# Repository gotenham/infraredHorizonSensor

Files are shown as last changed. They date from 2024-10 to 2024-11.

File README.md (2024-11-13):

# infraredHorizonSensor
A project to build a prototype infrared horizon sensor using a thermopile imaging array for CubeSat orbital attitude determination.

Check out the [video presentation summarising the research here](https://youtu.be/ipN0h2YGPOc?si=D6N8nWLN3bS8p15P).

Traditional image-based horizon sensors provide orientation information by detecting planetary edges against the background of space, a process often performed using visible light cameras due to the typically limited resolution of infrared imaging sensors. This study illustrates some of the advantages of using the infrared band for horizon detection, and explores recent advancements in sub-pixel edge localisation techniques, specifically the Zernike polynomials, to improve the performance of low-resolution thermal imaging sensors for horizon detection. To evaluate the utility of this technique, a prototype infrared horizon sensor and simulated infrared orbital view test stand was built to assess its performance.

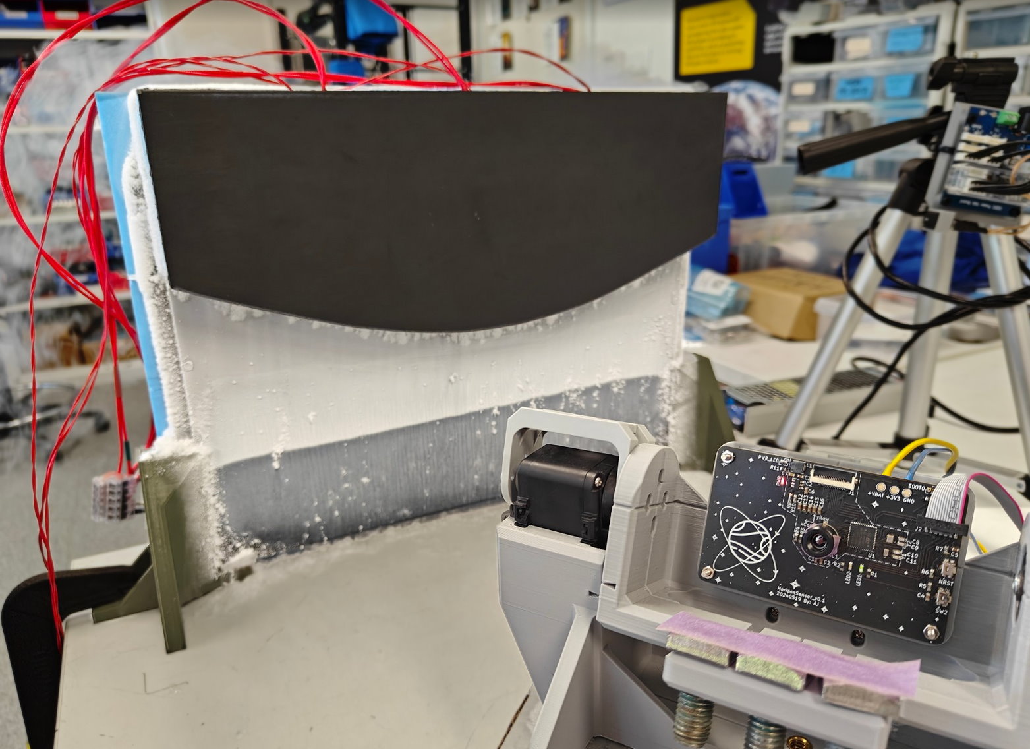
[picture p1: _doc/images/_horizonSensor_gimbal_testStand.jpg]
Simulated infrared orbital horizon view, and horizon sensor prototype mounted to pitch-roll gimbal


## Further Details
See research thesis at: [Infrared Horizon Sensor Thesis.pdf](_doc/_InfraredHorizonSensorThesis.pdf)

## Examples

*Infrared horizon sensor and example orbital attitude determination of planets nadir vector:*
<p align="left">
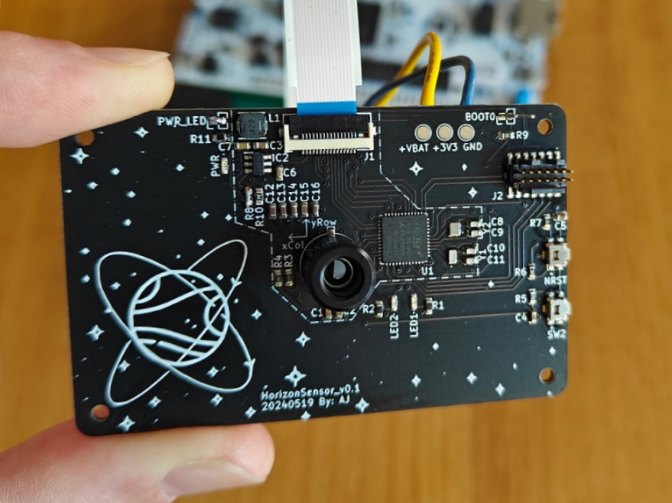
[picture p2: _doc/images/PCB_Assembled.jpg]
Prototype infrared horizon sensor PCB
  
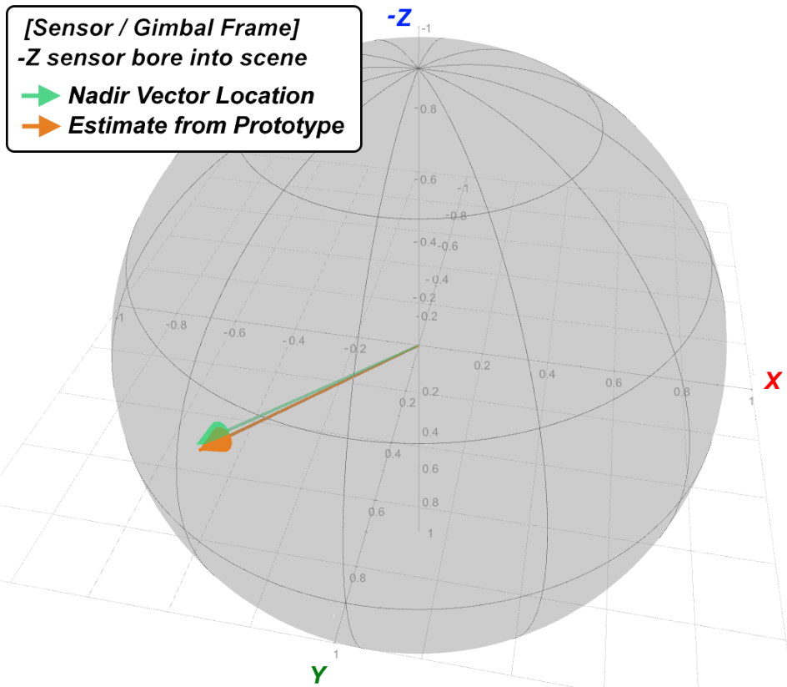
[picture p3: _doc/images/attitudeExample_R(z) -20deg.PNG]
example nadir vector relative attitude estimation
  
</p>

*Coarse pixel-level edge detection, image gradient vector field represented as 3D surface:*

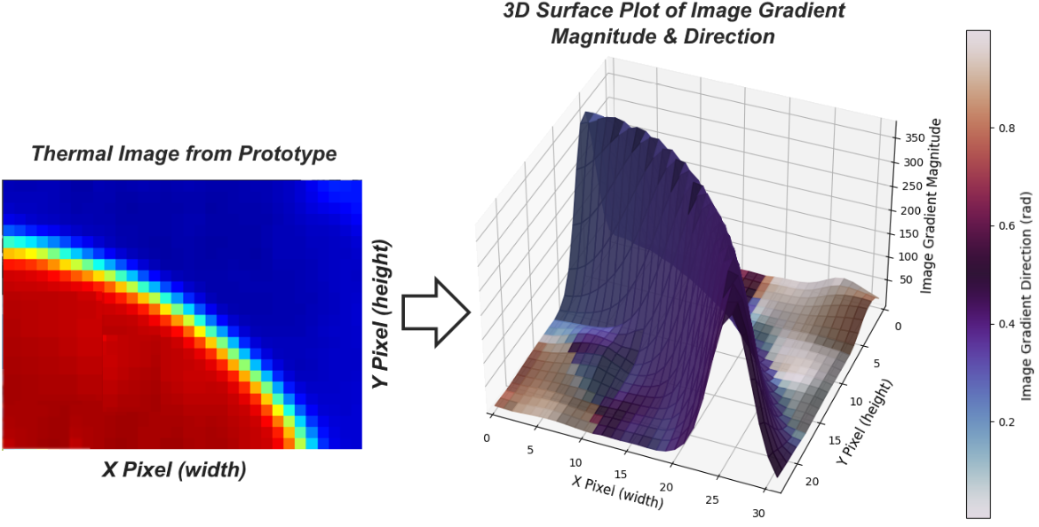
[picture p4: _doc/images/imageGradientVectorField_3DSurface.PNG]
Coarse edge detection image gradient vector field


*Example sub-pixel correction to detected pixel-level orbital horizon edge:* 

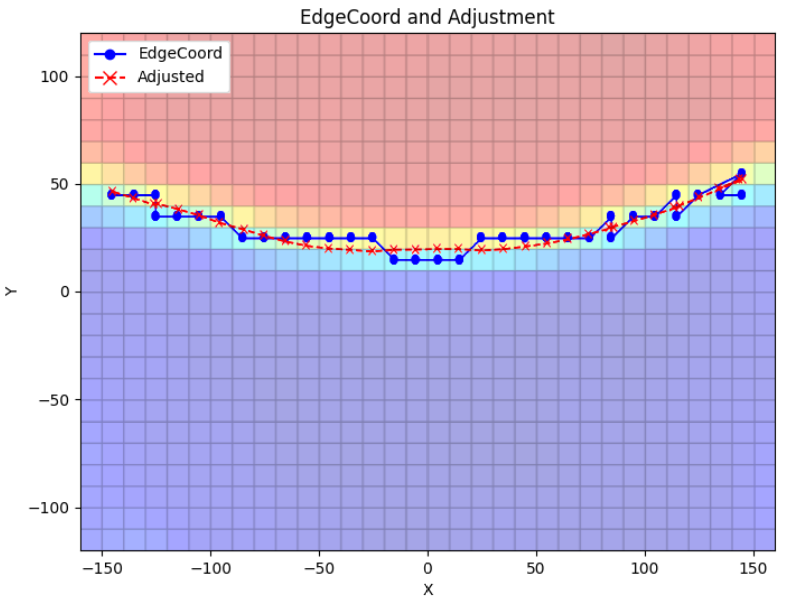
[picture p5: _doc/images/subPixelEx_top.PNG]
orbital horizon edge sub-pixel correction example 2

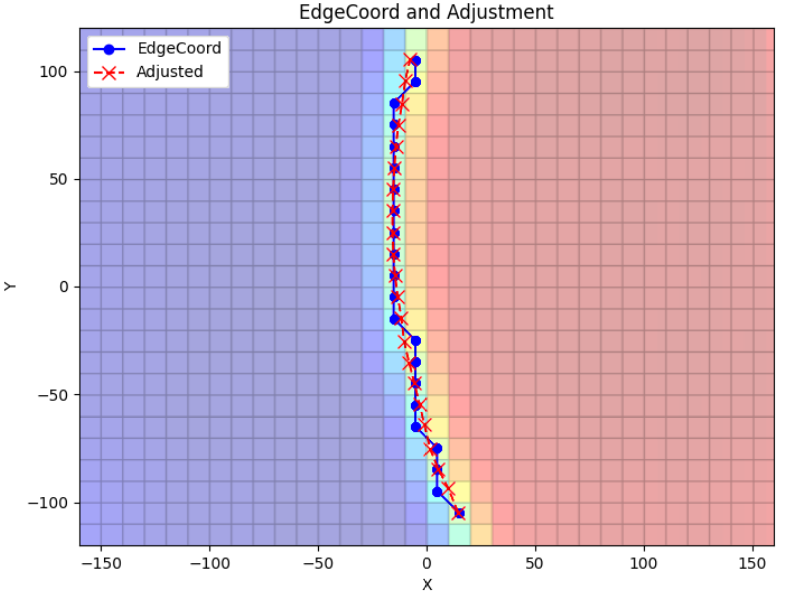
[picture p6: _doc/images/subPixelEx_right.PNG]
orbital horizon edge sub-pixel correction example 1

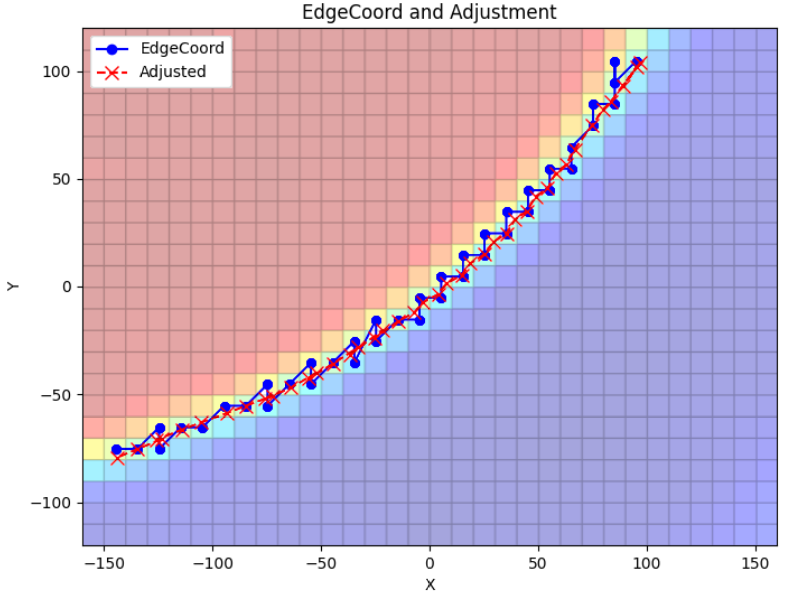
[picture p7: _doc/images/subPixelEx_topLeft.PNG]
orbital horizon edge sub-pixel correction example 3


*Example of Program Execution Flowchart:*

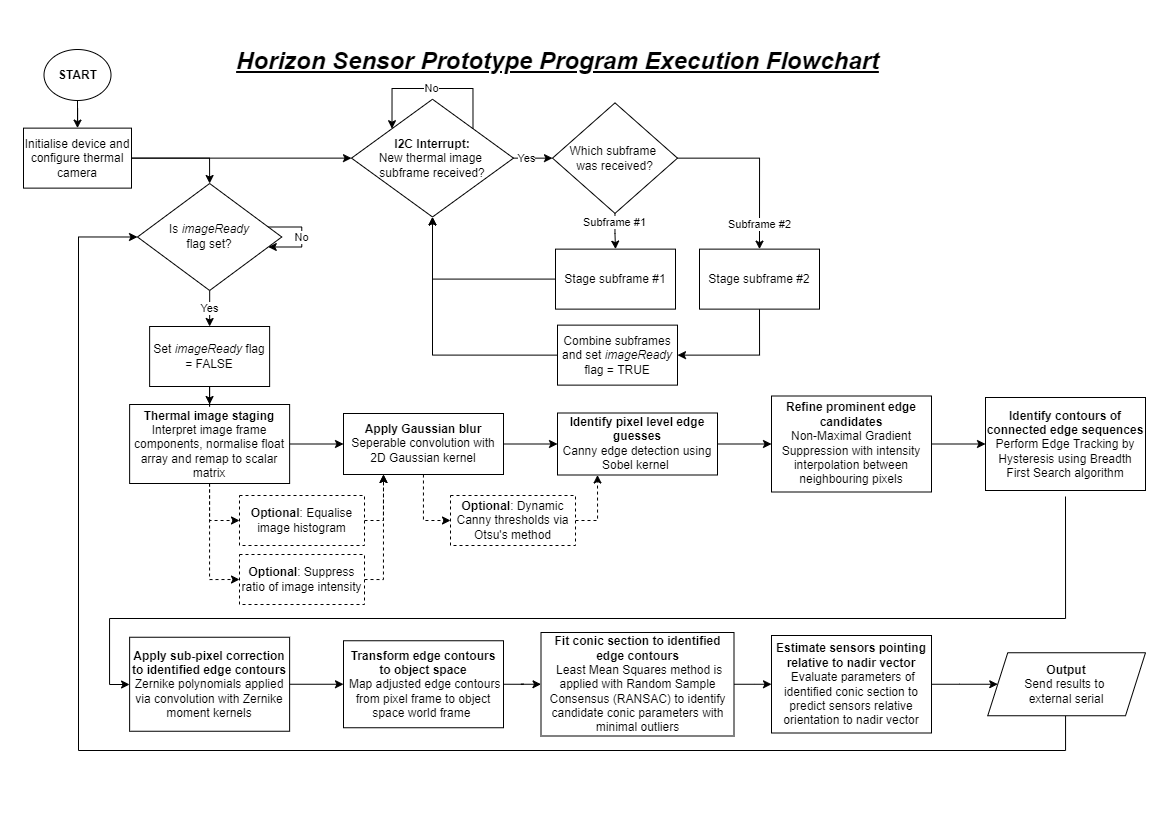
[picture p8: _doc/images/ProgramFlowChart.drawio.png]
Program Execution Flowchart


## Permissive Open-Source Licensing
- **Software**: Licensed under the permissive [MIT License](LICENSE-MIT).
- **Hardware Design Files**: Licensed under the [CERN-OHL-Permissive Open-Source License](LICENSE-CERN-OHL-P).

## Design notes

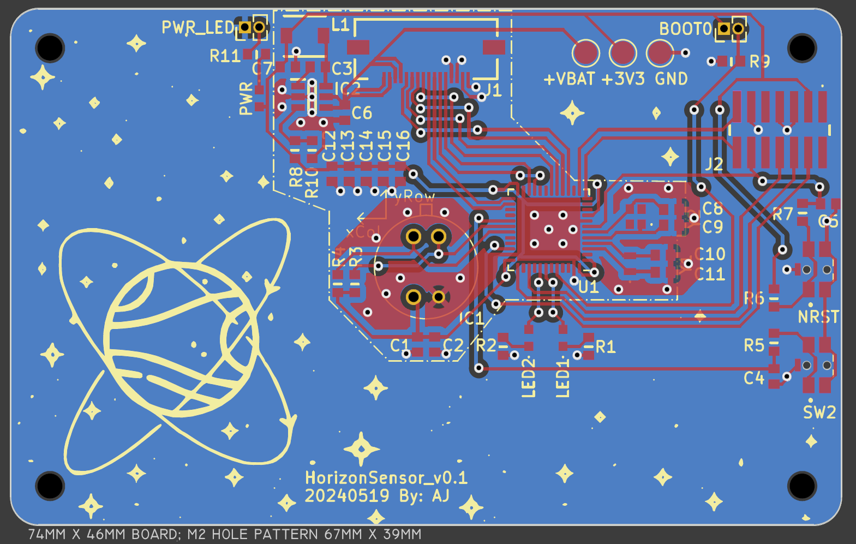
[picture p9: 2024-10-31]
device_pcb_design_files/PCB_Layout.png

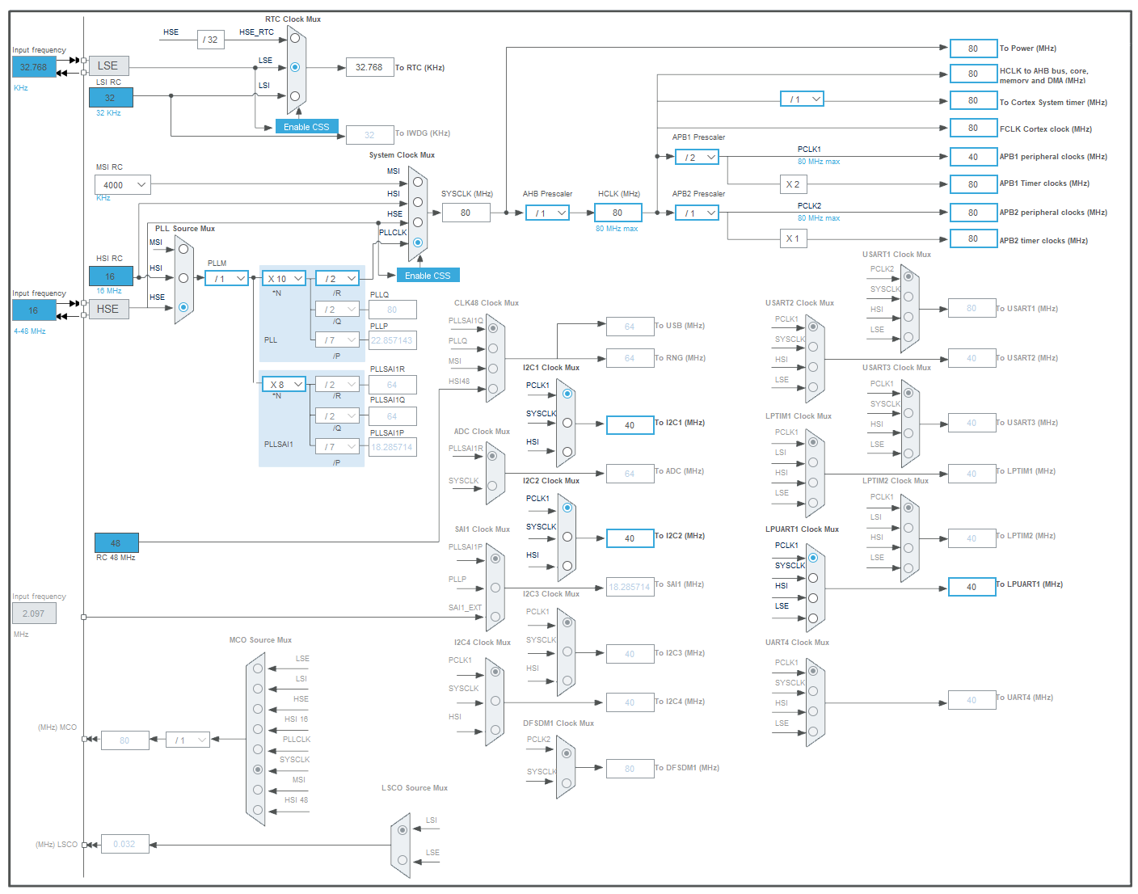
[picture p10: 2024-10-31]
device_pcb_design_files/STM32L4_ClockConfig.png

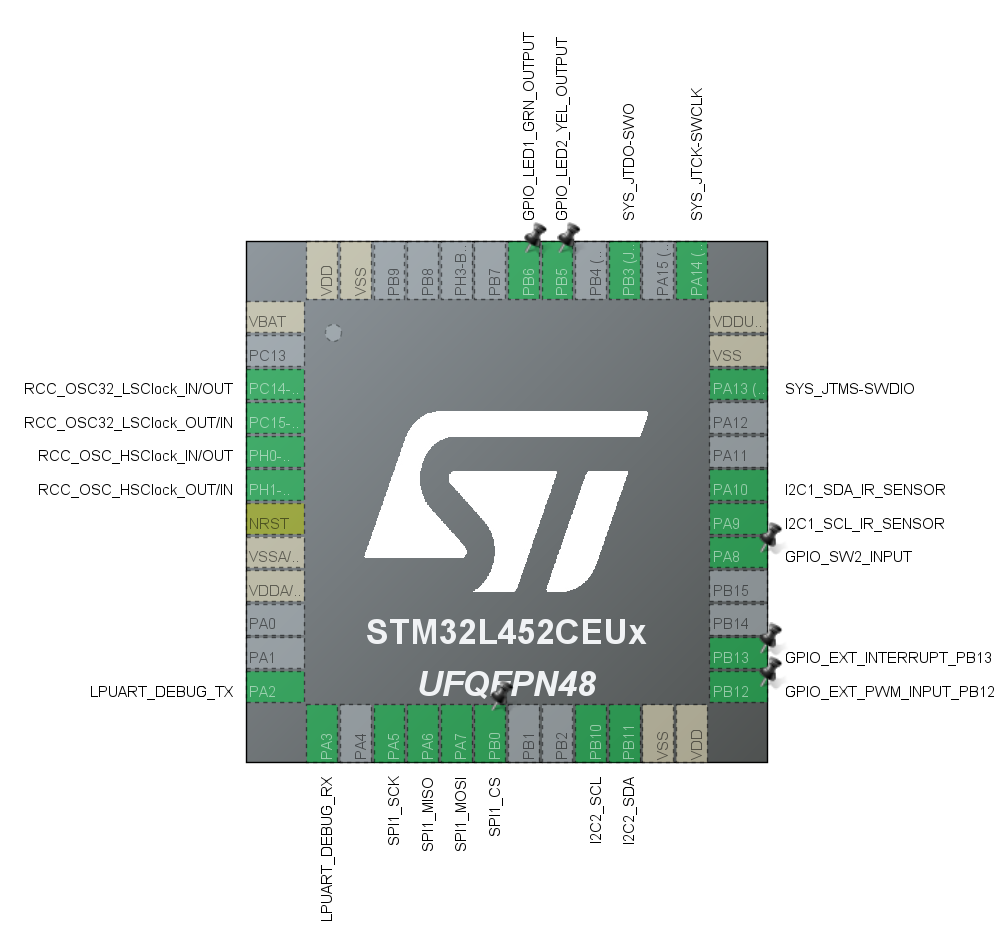
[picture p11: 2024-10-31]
device_pcb_design_files/STM32L4_PinConfig.png

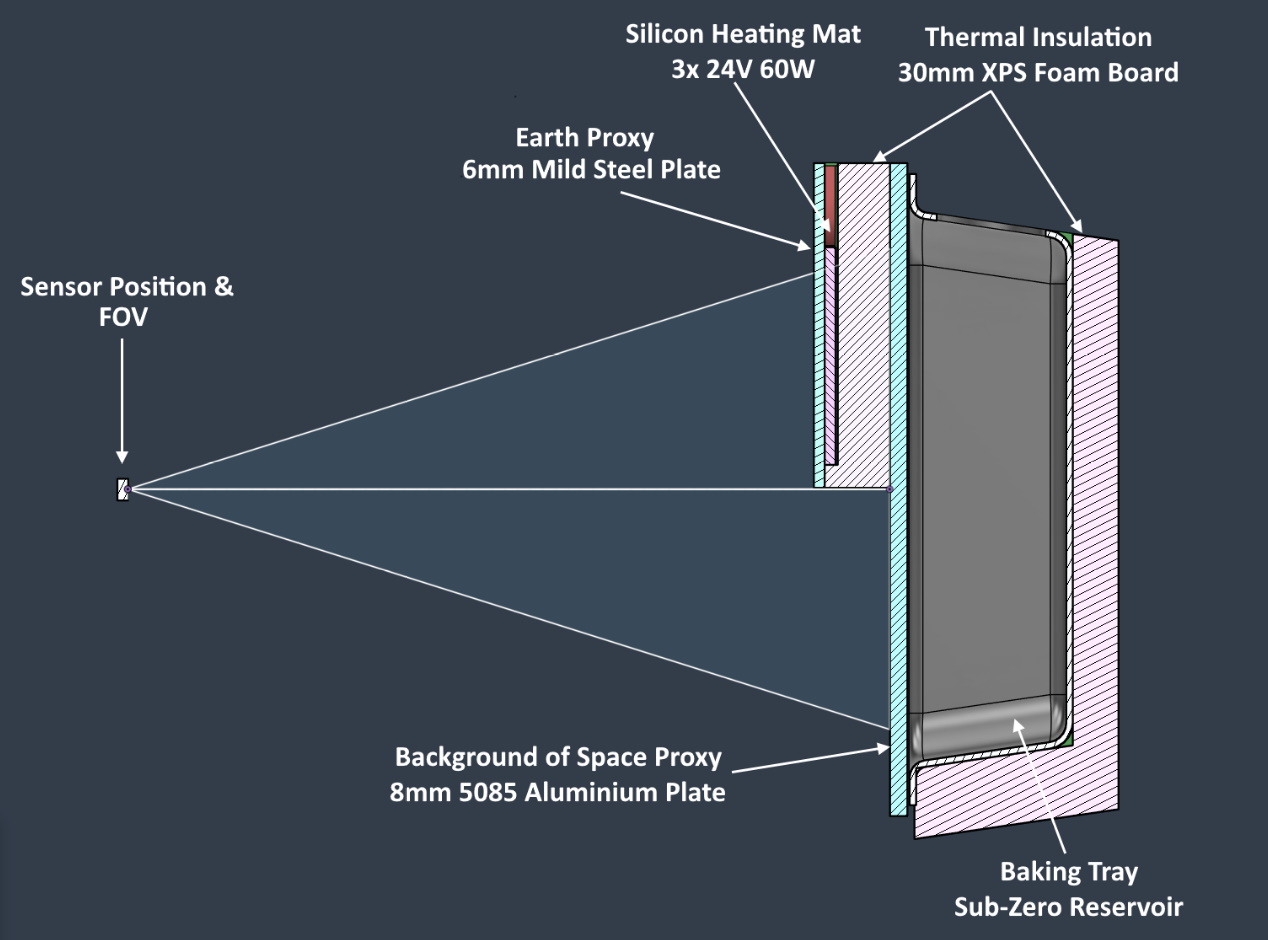
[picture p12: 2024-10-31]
_doc/images/proxy_orbital_view_side_section.jpg

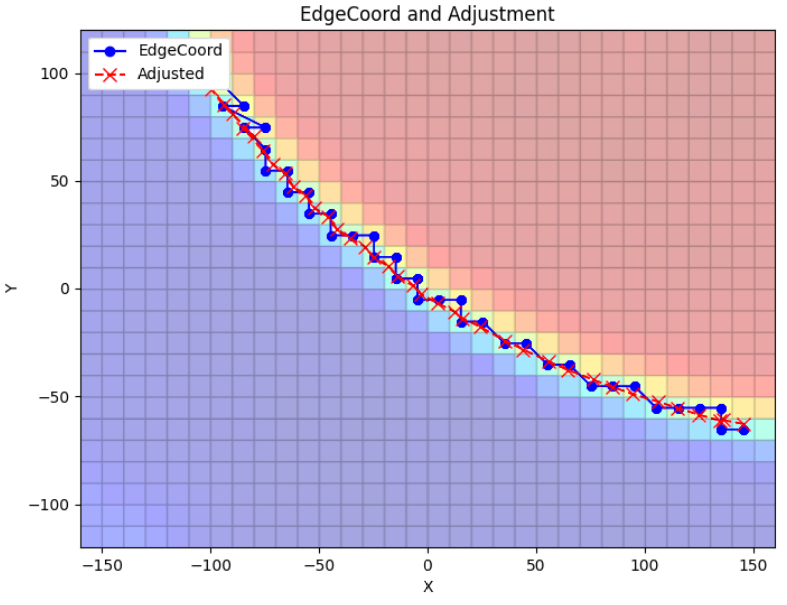
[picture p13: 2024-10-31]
_doc/images/subPixelEx_topRight.PNG

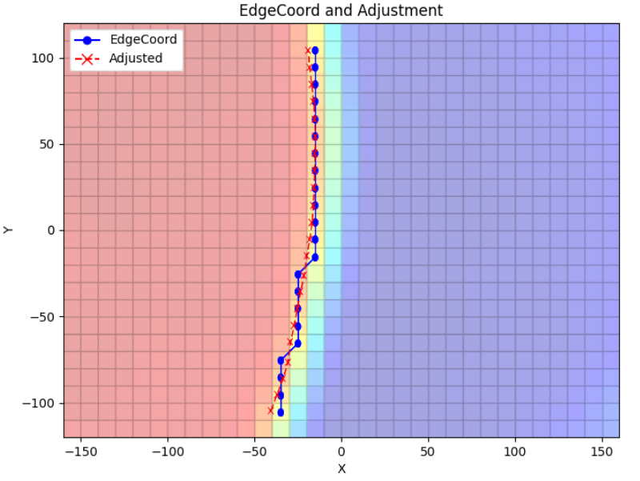
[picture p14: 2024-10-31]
_doc/images/subPixelEx_left.PNG

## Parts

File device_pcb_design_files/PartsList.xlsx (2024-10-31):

Current as of 12 Oct 2024.
Line# | Name | Description | Quantity | PCB Designator | Destination Type | Comment | Manufacturer | Manufacturer Part Number | Supplier | Supplier Part Number | Supplier Unit Price | Supplier Subtotal
1 | ARM Microcontroller STM32-L4-52CE | Ultra-low-power Arm Cortex-M4 32-bit MCU+FPU, 100DMIPS, up to 512KB Flash, 160KB SRAM | 1 | U1 | Microcontroller | Main board controller | STMElectronics | STM32L452CEU6 | Mouser | 511-STM32L452CEU6 (https://au.mouser.com/ProductDetail/STMicroelectronics/STM32L452CEU6?qs=ObEXV34I18O%2FVMhx%252BuvyYg%3D%3D) | $11.48 | $11.48
2 | IR Array MLX90640-BAB | Melexis MLX90640-BAB 32x24 IR Array FOV: 55°x35°, TO39 package; OR MLX90640-BAA for FOV: 110°x55° | 1 | IC1 | Input: IR Sensor | 32x24px IR array; I2C 400kHz (FastMode) or 1MHz (FastMode+) Interface; 3V3 input supply | Melexis | MLX90640ESF-BAB-000-SP | Mouser | 482-MLX90640ESFBABSP (https://au.mouser.com/ProductDetail/Melexis/MLX90640ESF-BAB-000-SP?qs=y6ZabgHbY%252BwqHrvRZCHRaw%3D%3D) | $73.59 | $73.59
3 | Crystal ECS-160-10-37B2-CTN-TR | Crystals 16.000 MHz 10 pF +/-10 +/-20 -40 +85 C +/-2 ppm Max. ESR = 150 | 1 | Y2 | Oscillator: High Speed | high speed external oscillator; main clock source for microcontroller, feeds I2C etc frequency. | ECS | ECS-160-10-37B2-CTN-TR | Mouser | 520-160-10-37B2CTNTR (https://au.mouser.com/ProductDetail/ECS/ECS-160-10-37B2-CTN-TR?qs=QNEnbhJQKvYELA%252BmNCGPQg%3D%3D) | $0.60 | $0.60
4 | Capacitor 8.2 pF 10% 50 V 0603 | Chip Capacitor, 8.2 pF, 10%, 50 V, 0603 (1608 Metric) | 2 | C8, C9 | Oscillator: High Speed | high speed oscillator caps; Murata GCM1885C2A8R2DA16D OR Yageo CC0603JRNPO9BN8R2 | Murata Electronics | GCM1885C2A8R2DA16D | Mouser | 81-GCM1885C2A8R2DA6D (https://au.mouser.com/ProductDetail/Murata-Electronics/GCM1885C2A8R2DA16D?qs=ui%252B2d9lVEI6Kkl8VJlb6yg%3D%3D) | $0.19 | $0.38
5 | Crystal ECS-.327-6-12-TR | Parallel - Fundamental Quartz Crystal, 0.032768MHz Nom | 1 | Y1 | Oscillator: Low Speed | low speed external oscillator for real-time clock (RTC) functions; maintains accurate timekeeping in low-power modes. | ECS | ECS-.327-6-12-TR | Mouser | 520-ECS-.327-6-12-TR (https://au.mouser.com/ProductDetail/ECS/ECS-.327-6-12-TR?qs=wo4x%252BUeoG8V%252B%252BoaFHDz4HA%3D%3D) | $1.04 | $1.04
6 | Capacitor 3.9 pF 10% 50 V 0603 | Chip Capacitor, 3.9 pF, 10%, 50 V, 0603 (1608 Metric) | 2 | C10, C11 | Oscillator: Low Speed | low speed oscillator caps | Murata Electronics | GCM1885C1H3R9CA16D | Mouser | 81-GCM1885C1H3R9CA6D (https://au.mouser.com/ProductDetail/Murata-Electronics/GCM1885C1H3R9CA16D?qs=ui%252B2d9lVEI4nHm76rfY3Bw%3D%3D) | $0.34 | $0.69
7 | Voltage Regulator +3V3 Output; 6-36V Input | Switching Voltage Regulators SIMPLE SWITCHER® 36-V, 600-mA Buck Regulator With High-Efficiency Sleep Mode 6-SOT-23 -40 to 125 | 1 | IC2 | Voltage Regulator | +3V3 voltage regulator | Texas Instruments | TPS560430X3FDBVR | Mouser | TPS560430X3FDBVR (https://au.mouser.com/ProductDetail/Texas-Instruments/TPS560430X3FDBVR?qs=y6ZabgHbY%252Bzg1UxrVv3WVw%3D%3D) | $1.68 | $1.68
8 | Inductor L 12uH | Power Inductors - SMD 12 UH 20% | 1 | L1 | Inductor L | voltage reg supplementary hardware | Murata | 1231AS-H-120M=P3 | Mouser | 1231AS-H-120M=P3 (https://au.mouser.com/ProductDetail/Murata-Electronics/1231AS-H-120M%3dP3?qs=4tuKoHGzn10isROk6q9tqQ%3D%3D) | $1.24 | $1.24
9 | Capacitor C_out 22uF; 10V | Multilayer Ceramic Capacitors MLCC - SMD/SMT 22 uF 10 VDC 20% 0603 X5R | 1 | C7 | Capacitor C_out | voltage reg supplementary hardware | Murata | GRM188R61A226ME15D | Mouser | GRM188R61A226ME15D (https://au.mouser.com/ProductDetail/Murata-Electronics/GRM188R61A226ME15D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) | $0.31 | $0.31
10 | Capacitor C_boot 0.1uF | Multilayer Ceramic Capacitors MLCC - SMD/SMT 0.1 uF 50 VDC 10% 0603 X7R AEC-Q200 | 1 | C3 | Capacitor C_boot | voltage reg supplementary hardware | Murata | GCJ188R71H104KA12D | Mouser | GCJ188R71H104KA12D (https://au.mouser.com/ProductDetail/Murata-Electronics/GCJ188R71H104KA12D?qs=zThidflJDvYKuGhiQaflUg%3D%3D) | $0.20 | $0.20
11 | Capacitor C_in 2.2uF | Multilayer Ceramic Capacitors MLCC - SMD/SMT 2.2 uF 16 VDC 10% 0603 X6S | 1 | C6 | Capacitor C_in | voltage reg supplementary hardware | Murata | GRM188C81C225KA12D | Mouser | GRM188C81C225KA12D (https://au.mouser.com/ProductDetail/Murata-Electronics/GRM188C81C225KA12D?qs=O5cugoO6nwevZQeqg2lgHQ%3D%3D) | $0.16 | $0.16
12 | Capacitor 10 uF +/- 10% 16 V 0603 | Ceramic Capacitors MLCC - SMD/SMT 10 uF 16 VDC 10% 0603 X5R AEC-Q200 | 2 | C2, C12 | Supply / Input Sup | IR sensor / voltage conditioning | Murata Electronics | GRT188R61C106KE13D | Mouser | 81-GRT188R61C106KE3D (https://au.mouser.com/ProductDetail/Murata-Electronics/GRT188R61C106KE13D?qs=drgMNd%252BkGPNdAIGHCKvRGQ%3D%3D) | $0.58 | $1.16
13 | Capacitor 100 nF +/-10% 50 V 0603 | Ceramic Capacitors SMD/SMT 0.1 uF 25 VDC 10% 0603 X8R AEC-Q200 | 7 | C1, C4, C5, C13, C14, C15, C16 | Supply / Input Sup | IR sensor / switch / voltage conditioning | Murata Electronics | GCM188R91E104KA37D | Mouser | 81-GCM188R91E104KA7D (https://au.mouser.com/ProductDetail/Murata-Electronics/GCM188R91E104KA37D?qs=fYnTpiIxukKBCa2bT2%252Bflw%3D%3D) | $0.25 | $1.76
14 | Resistor 1k +/-1% 0603 100 mW | Chip Resistor, 1 kOhm, +/- 1%, 100 mW, -55 to 155 degC, 0603 (1608 Metric) | 2 | R3, R4 | Input Sup | IR sensor (2x as per I2C spec, MLX90640 datasheet) | Vishay | CRCW06031K00FKEAC | Mouser | 71-CRCW06031K00FKEAC (https://au.mouser.com/ProductDetail/Vishay-Dale/CRCW06031K00FKEAC?qs=E3Y5ESvWgWOQ7ePIWbGVFg%3D%3D) | $0.16 | $0.31
15 | Connector Molex 505110-1692 | Conn FFC/FPC Connector SKT 16 POS 0.5mm Solder RA SMD Easy-On T/R | 1 | J1 | Conn External | external interboard interface connection | Molex | 505110-1692 | Mouser | 538-505110-1692 (https://au.mouser.com/ProductDetail/Molex/505110-1692?qs=RawsiUxJOFQybAcXh3htqQ%3D%3D) | $1.30 | $1.30
16 | Connector Header Strip STDC14 | STDC14 for STLINK Programmer | 1 | J2 | Conn External | STLINK Debug connection | Samtec | FTSH-107-01-L-DV-K | Mouser | 200-FTSH10701LDVK (https://au.mouser.com/ProductDetail/Samtec/FTSH-107-01-L-DV-K?qs=%252BZP6%2F%252BtExtBNGLAeWROTVA%3D%3D) | $7.21 | $7.21
17 | Switch PTS840GKPSMTRLFS | Keypad Switch, 1 Switches, SPST, Momentary-tactile, 0.05A, 12VDC, 2.94N, Solder Terminal, Surface Mount-right Angle | 2 | SW1, SW2 | Input: Switch | NRST / SW2 | C&K | PTS840GKPSMTRLFS | Mouser | 611-PTS840GKPSMTR (https://au.mouser.com/ProductDetail/CK/PTS840GKPSMTRLFS?qs=UxeAxwACbqkq7SgpXXj12Q%3D%3D) | $0.72 | $1.44
18 | Resistor 620 +/-1% 0603 100 mW | Thick Film Resistors - SMD 620 Ohms 100 mW 0603 1% AEC-Q200 | 2 | R5, R7 | Input Sup | NRST / SW2 input supplementary hardware | Yageo | AC0603FR-07620RL | Mouser | 603-AC0603FR-07620RL (https://au.mouser.com/ProductDetail/YAGEO/AC0603FR-07620RL?qs=yhV1fb9g%2FKaLU%252BaeSkSsYg%3D%3D) | $0.16 | $0.31
19 | Resistor 10k +/-1% 0603 100 mW | Thick Film Resistors - SMD 10 kOhms 100mW 0603 1% AEC-Q200 | 2 | R6, R9 | Input Sup | NRST / BOOT0 input supplementary hardware | Yageo | AC0603FR-0710KL | Mouser | 603-AC0603FR-0710KL (https://au.mouser.com/ProductDetail/YAGEO/AC0603FR-0710KL?qs=UoPT7wUmgYKz3zh0UDMA4Q%3D%3D) | $0.16 | $0.31
20 | LED Green LG L29K-G2J1-24 | LED Green, Diffused, 0603, 2mA | 1 | LED1 | Output: LED | LED status indicator | AMS OSRAM | LG L29K-G2J1-24 | Mouser | 720-LGL29KG2J124Z (https://au.mouser.com/ProductDetail/ams-OSRAM/LG-L29K-G2J1-24?qs=%252BEew9%252B0nqrDT522vbrqDjw%3D%3D) | $0.71 | $0.71
21 | LED Orange LO L29K-H2K1-24 | LED Orange, Diffused, 0603, 2mA | 1 | LED2 | Output: LED | LED status indicator | AMS OSRAM | LO L29K-H2K1-24 | Mouser | 720-LOL29KH2K124Z (https://au.mouser.com/ProductDetail/ams-OSRAM/LO-L29K-H2K1-24?qs=%252BEew9%252B0nqrDE9qlFl9lmFg%3D%3D) | $0.66 | $0.66
22 | LED Red LSL29K-G1J2-1-Z | LED Red, Diffused, 0603, 2mA | 1 | PWR_LED | Output: LED | LED status indicator | AMS OSRAM | LS L29K-G1J2-1 | Mouser | 720-LSL29K-G1J2-1-Z (https://au.mouser.com/ProductDetail/ams-OSRAM/LS-L29K-G1J2-1?qs=NTcu%252BMSV%252BkPRbJMh%252BPhU8g%3D%3D) | $0.58 | $0.58
23 | Resistor 3.3k +/-1% 0603 100 mW | Chip Resistor, 3.3 kOhm, +/- 1%, 100 mW, -55 to 155 degC, 0603 (1608 Metric) | 3 | R1, R2, R11 | Output Sup: LED | LED supplementary hardware (1mA @ 3v3, 1.5mA @ 5V) | Vishay | CRCW06033K30FKEA | Mouser | 71-CRCW0603-3.3K-E3 (https://au.mouser.com/ProductDetail/Vishay-Dale/CRCW06033K30FKEA?qs=1ghF3ZI8kS8fRqapjAj84Q%3D%3D) | $0.16 | $0.47
 |  |  | 38 |  |  |  |  |  |  |  |  | $107.60

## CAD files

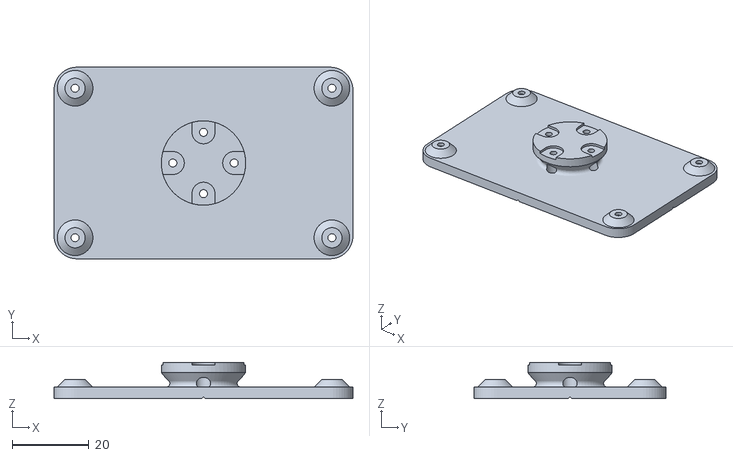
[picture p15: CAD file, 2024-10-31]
test_stand_design_files/pitch_roll_gimbal/stl/RollAxisStructure_v66.stl
78.0 x 50.0 x 9.50

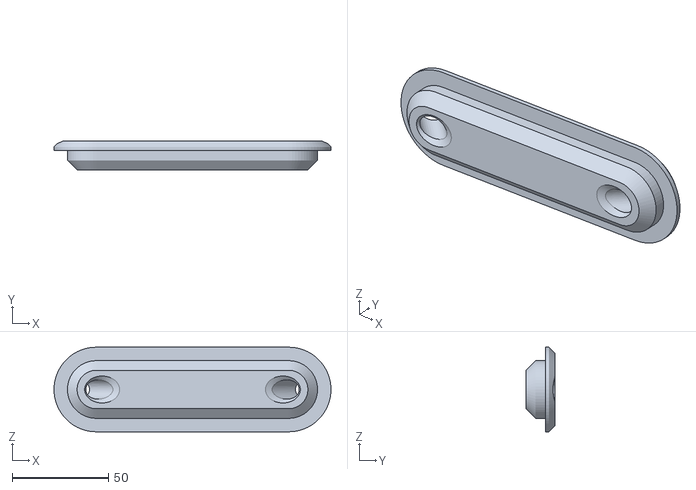
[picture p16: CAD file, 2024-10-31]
test_stand_design_files/proxy_orbital_view/stl/ReservoirCap_v11.stl
144.0 x 15.0 x 44.0

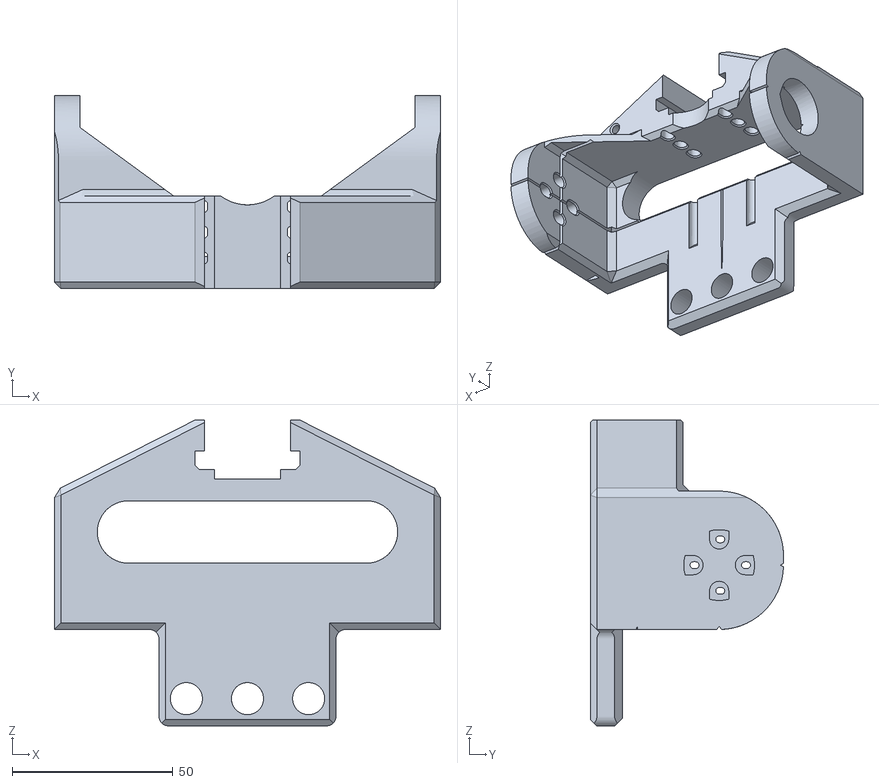
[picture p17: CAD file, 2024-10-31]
test_stand_design_files/pitch_roll_gimbal/stl/PitchAxisStructure_v66.stl
120.0 x 60.0 x 95.1

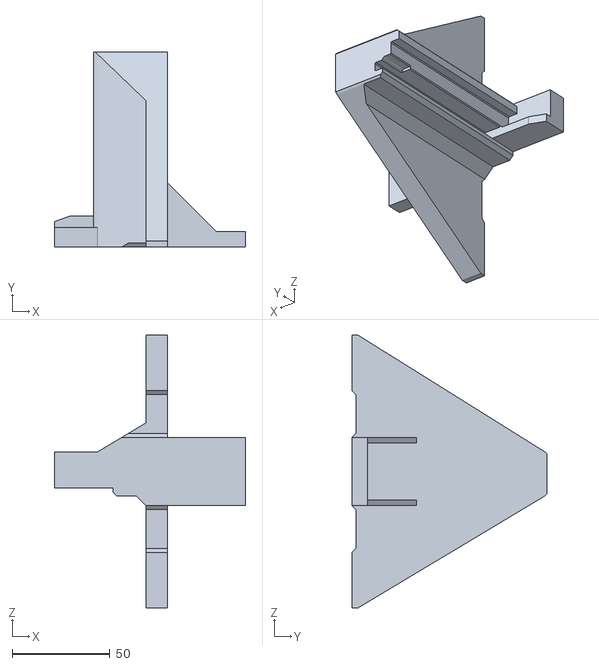
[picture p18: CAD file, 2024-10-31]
test_stand_design_files/proxy_orbital_view/stl/TestStand_SupportStruct_R_v13.stl
98.0 x 100.0 x 140.0

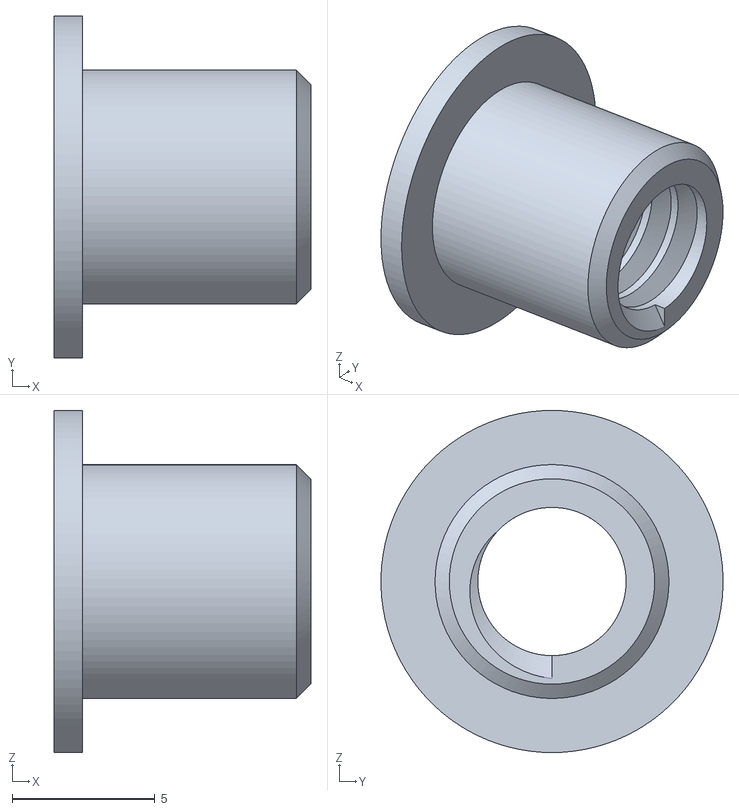
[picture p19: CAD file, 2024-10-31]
test_stand_design_files/pitch_roll_gimbal/stl/BearingSpacerInsert_v55.stl
9.00 x 12.0 x 12.0

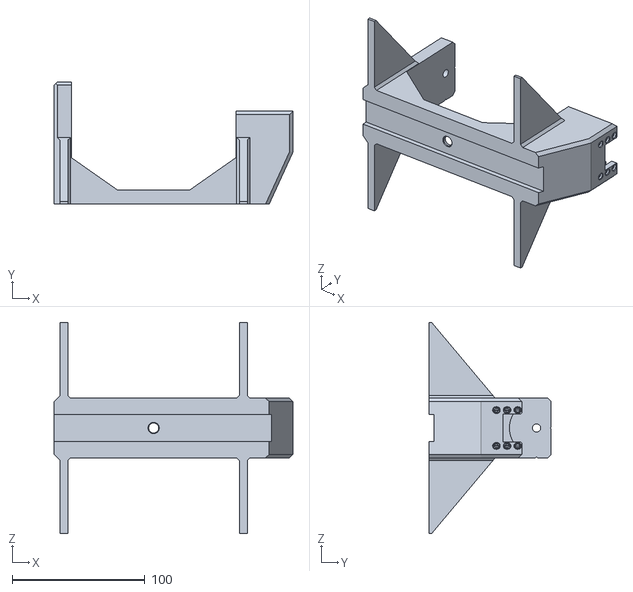
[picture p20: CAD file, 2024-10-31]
test_stand_design_files/pitch_roll_gimbal/stl/BaseStructure_v55.stl
179.9 x 92.0 x 159.1

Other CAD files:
test_stand_design_files/proxy_orbital_view/stl/TestStand_SupportStruct_L_v13.stl

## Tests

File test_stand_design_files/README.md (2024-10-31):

Refer to thesis sections "2.3 Orbital View Test Stand"
To assess the utility of the prototype infrared horizon sensor, a simulated infrared view of Earths orbital horizon was designed;
with the following configuration:
	a) LEO orbital altitude of 600-800km;
	b) 55° x 35° sensor FOV;
	c) Viewed from the nominal orientation.
	
The prototype was mounted to a controllable pitch and roll gimbal while viewing the simulated orbital view. 
By adjusting the sensors roll and pitch by known quantities, the horizon sensors attitude estimation relative to the nadir vector of the simulated view can be evaluated.
The final test stand is comprised of two key components, the proxy infrared orbital view that the prototype will perceive, and the controllable pitch-roll gimbal 
that the prototype is mounted within; the design considerations of both are detailed in thesis sections "2.3 Orbital View Test Stand".

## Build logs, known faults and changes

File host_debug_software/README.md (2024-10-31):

Refer to thesis sections "2.2.3 Host Device Viewing Software":
run from terminal and specify COM port, either 'COMx' or 'x' work.
```python
# Example
python .\receive_serial.py 6
# or
python .\receive_serial.py COM6

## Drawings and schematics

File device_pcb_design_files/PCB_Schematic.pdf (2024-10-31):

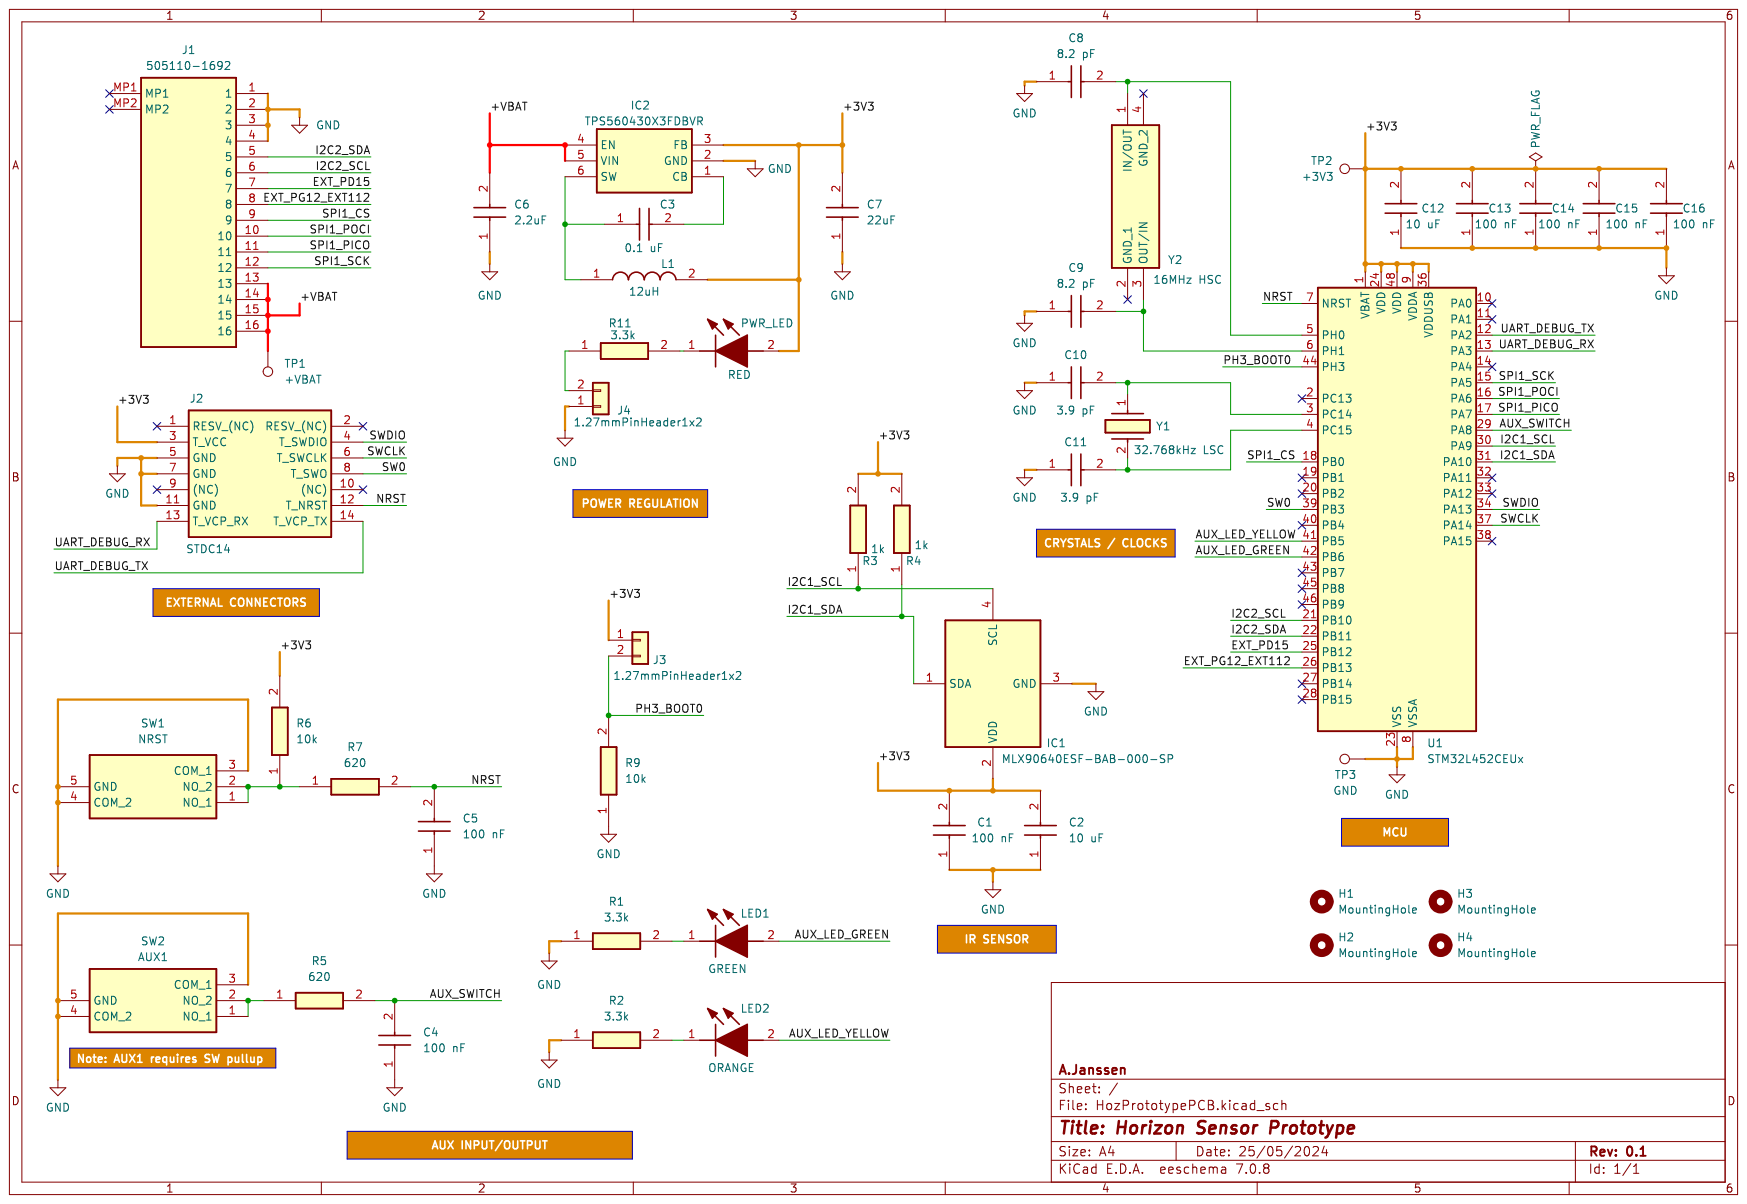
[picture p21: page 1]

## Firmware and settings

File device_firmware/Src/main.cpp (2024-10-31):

/* Includes ------------------------------------------------------------------*/
#include "main.h"

/* USER CODE BEGIN Includes */
#include <stdio.h>
#include "retarget.h"
#include "MLX90640_API.h"
#include "MLX90640_I2C_Driver.h"
#include "mtxCV.h"

/* USER CODE END Includes */

/* USER CODE BEGIN PD */
#define _DEBUG_MAIN //DEBUG FLAG, uncomment to enable module debugging
//#define _DEBUG_SENSOR //DEBUG FLAG, uncomment to enable module debugging related to sensor init

#define MLX_EEPROM_SIZE 832
#define MLX_FRAME_DATA_SIZE 834
#define MLX_THERMAL_ARR_SIZE 768

#define IMAGE_WIDTH 32
#define IMAGE_HEIGHT 24
/* USER CODE END PD */

I2C_HandleTypeDef hi2c1;
I2C_HandleTypeDef hi2c2;

UART_HandleTypeDef hlpuart1;

RTC_HandleTypeDef hrtc;

SPI_HandleTypeDef hspi1;

/* USER CODE BEGIN PV */
const uint8_t MLX90640_address = 0x33; // 0x33 default 7-bit unshifted address of the MLX90640

const uint8_t gaussian_N = 5; // SET Gaussian NxN kernel size, must be odd
const RowVector<float, (int)gaussian_N> gaussianRowVector = (Eigen::RowVector<float, (int)gaussian_N>() <<
		0.070766f, 0.244460f, 0.369546f, 0.244460f, 0.070766f).finished();
const Vector<float, (int)gaussian_N> gaussianColVector = (Eigen::Vector<float, (int)gaussian_N>() <<
		0.070766f, 0.244460f, 0.369546f, 0.244460f, 0.070766f).finished(); // TBD::wasting memory given transpose of row vect

// add your relevent intrinsicK_inv params below from sensor calibration
const Matrix3f intrinsicK_inv = (Eigen::Matrix3f() <<
		1.f,	0, 		-16.f,
		0,		-1.f, 	12.f,
		0,		0, 		1.f).finished();

const float cannyGradientThreshHigh = 0.7f; // ratio of largest gradient in suppressed image; edge must have gradient >= this to qualify as strong edge
const float cannyGradientThreshLow = 0.3f; // ratio of {cannyGradientThreshHigh OR largest gradient in suppressed image}, edge must have gradient >= this to qualify a weak edge
const size_t minSequenceLength = 10; //minimum sequence of edge points required to qualify being added to edgeSequenceListReturn
const uint8_t strongEdgeValue = 255; // candidate edges are assigned this value in the canny returned edgeMask when >= calculated dynThreshHigh
const uint8_t weakEdgeValue = 160; // candidate edges are assigned this value in the canny returned edgeMask when >= calculated dynThreshLow

/* USER CODE END PV */

void SystemClock_Config(void);
static void MX_GPIO_Init(void);
static void MX_I2C1_Init(void);
static void MX_I2C2_Init(void);
static void MX_LPUART1_UART_Init(void);
static void MX_SPI1_Init(void);
static void MX_RTC_Init(void);
/* USER CODE BEGIN PFP */

// FUNCTION SIGNATURES IN MAIN
bool initialise_MLX90640(const uint8_t& I2C_address, paramsMLX90640& _paramsTarget); // combines initialisation steps and avoids storing eeData longer than required
int getFrame_MLX90640(const uint8_t& I2C_address, float *_imgArr, float& _ta, paramsMLX90640& _params);
void sendGraphCoords(const vector<EdgePoint*>& edgeContour); // Helper function to send edge sequence to serial, to display as graph on host machine
void sendSerialData(const uint8_t* data, uint16_t size);
template<typename MatrixType>
void sendMatrixSerial(const MatrixType& matrix, const char* uniqueTitle);
unsigned int getSysTickSeed(void); //generates "random" number as ms since system was rebooted (used for RANSAC input seed)

/* USER CODE END PFP */

/**
  * @brief  The application entry point.
  * @retval int
  */
int main(void)
{

	/* MCU Configuration--------------------------------------------------------*/

	/* Reset of all peripherals, Initializes the Flash interface and the Systick. */
	HAL_Init();

	/* Configure the system clock */
	SystemClock_Config();

	/* Initialize all configured peripherals */
	MX_GPIO_Init();
	MX_I2C1_Init();
	MX_I2C2_Init();
	MX_LPUART1_UART_Init();
	MX_SPI1_Init();
	MX_RTC_Init();
	/* USER CODE BEGIN 2 */

	//Retarget various serial print commands, gives printf functionality to COM port serial for debugging
	RetargetInit(&hlpuart1);

	MLX90640_I2CGeneralReset(); //send general reset command to reset connected I2C devices
	HAL_Delay(200); // allow startup settling

	// Configure MLX90640_I2C_Driver.h with reference to IC2 interface it should use; ie hi2c1
	MLX90640_I2CInitRef(&hi2c1);

	#ifdef _DEBUG_MAIN
		printf("\n\r\n\r-------------------------------- RESET --------------------------------\n\r");
		printf(">> Serial Debug Started @%lubaud <<\n\r", hlpuart1.Init.BaudRate); // default: 115200
	#endif

	/* Key sensor related data storage */
	paramsMLX90640 mlx90640Params; //struct stores sensor configuration and mapping parameters recieved from device
	float mlx90640ImageArr[MLX_THERMAL_ARR_SIZE]; // MAIN storage for returned 1-D thermal array from sensor

	/* Perform initialisation for thermal sensor */
	if(!initialise_MLX90640(MLX90640_address, mlx90640Params)){
		#ifdef _DEBUG_MAIN
			printf("\n\rFAILED TO INIT MLX90640, freezing..");
		#endif
		//Set yellow LED ON to indicate startup error
		HAL_GPIO_WritePin(GPIOB, GPIO_LED2_YEL_OUTPUT_Pin, GPIO_PIN_SET);
		HAL_GPIO_WritePin(GPIOB, GPIO_LED1_GRN_OUTPUT_Pin, GPIO_PIN_RESET);
		while (1); //freeze program execution // TBD for debugging
	} else {
		#ifdef _DEBUG_MAIN
			printf("OK: MLX90640 Sucessfully Initialised!\n\r");
		#endif
		//Set green LED ON to indicate startup OK
		HAL_GPIO_WritePin(GPIOB, GPIO_LED2_YEL_OUTPUT_Pin, GPIO_PIN_RESET);
		HAL_GPIO_WritePin(GPIOB, GPIO_LED1_GRN_OUTPUT_Pin, GPIO_PIN_SET);
	}

	/* Setup main loop local variables */
	Matrix<float, IMAGE_HEIGHT, IMAGE_WIDTH> mtxThermal; // MAIN THERMAL IMAGE FRAME
	vector<EdgePoint> edgeCandidates; // init var to store coordinates of identified weak and strong edges in cannyEdgeDetection returned image edge mask
	//Matrix<int, IMAGE_HEIGHT, IMAGE_WIDTH> edgeMask; // MAIN EDGE MASK FRAME
	//MatrixXf mtxThermalNorm(IMAGE_HEIGHT, IMAGE_WIDTH); // MAIN NORMAL OF THERMAL IMAGE FRAME
	//Contours allContours; // init storage for Contours (eg a vector of edge sequences)
	vector<EdgePoint*> edgeContour;
	Matrix<float, 6, 1> best_conic; // Run RANSAC to fit a conic eq parameters into best_conic[A,B,C,D,E,F]
	float ta = -999.0; //used for temp offsets on MLX sensor (not used as currently reading direct pixel values instead of temperature calc)


	#ifdef _DEBUG_MAIN
		//printParamsMLX90640(&mlx90640Params);
	#endif

	/* USER CODE END 2 */

	/* Infinite loop */
	/* USER CODE BEGIN WHILE */
	while (1)
	{
		//Get new thermal image from sensor as 1D float array in mlx90640ImageArr
		getFrame_MLX90640(MLX90640_address, mlx90640ImageArr, ta, mlx90640Params);

		//Reset thermal image matrix
		mtxThermal.setZero();
		//Convert thermal image 1D array to 2D image matrix
		MtxCV::getByteMatrixFromFloatArray(mlx90640ImageArr, MLX_THERMAL_ARR_SIZE, mtxThermal); //, mtxThermalNorm

		// Send virgin thermal image to serial
		//sendMatrixSerial(mtxThermal, "mtxThermalVirgin");

		//perform convolution with seperable row anc col vectors, ie gaussian blur
		MtxCV::separableConvolution(mtxThermal, gaussianRowVector, gaussianColVector, true);

		// Perform canny edge detection with non-max suppression
		//MtxCV::cannyEdgeDetection(mtxThermal, edgeCandidates, cannyGradientThreshLow, cannyGradientThreshHigh, &edgeMask, weakEdgeValue, strongEdgeValue);
		//MtxCV::edgeTrackingByHysteresis(edgeMask, edgeCandidates, allContours, minSequenceLength, weakEdgeValue, strongEdgeValue);

		// BELOW IS TEMP helper fuction to reduce memory usage in main, it simply combinees the functionality of MtxCV::cannyEdgeDetection() and MtxCV::edgeTrackingByHysteresis()
		MtxCV::cannyTrackingHelperFn(mtxThermal, edgeCandidates, edgeContour, cannyGradientThreshLow, cannyGradientThreshHigh, weakEdgeValue, strongEdgeValue, minSequenceLength);

		//Generate subpixel coordinate adjustements for current edge sequence
		MtxCV::getZernikeSubpixelAdjustment(mtxThermal, edgeContour); // >> edgeContour.adjustment is the new coordinates after correction

		//Map sub-pixel coords to plane in world object space
		MtxCV::mapEdgeSequence2WorldFrame(edgeContour, intrinsicK_inv, 10.f); // >> edgeContour.adjustment and edgeContour.coord are the new coordinates after transform to object space

		//FLIP IMAGE HORIZONTAL + VERTICAL, inverts image to account for optical flip
		//mtxThermal.colwise().reverseInPlace();
		//mtxThermal.rowwise().reverseInPlace();

		//send thermal image via serial as renderable image
		sendMatrixSerial(mtxThermal, "mtxThermal"); // FYI: Flip image horizontally ( mtxThermal.colwise().reverse() )
		//sendMatrixSerial(edgeMask, "edgeMask");

		//Send the pixel edge and zernike sub-pixel adjusted coordinates to serial
		sendGraphCoords(edgeContour);

		//reset best conic params
		best_conic.setZero();
		unsigned int tickSeed = getSysTickSeed();
		// ransacConicFitting KEY::::{inputCoords, outputConicParams, eccentricity_minThreshold, numTestSamples, inlier_threshold(conic eq remainder must be less than this))}
		FnState fnFitConicModel = MtxCV::ransacConicFitting(edgeContour, best_conic, 1.f, 3.f, 100, 0.1f, tickSeed); //

		if(fnFitConicModel == FnState::OK){
			#ifdef _DEBUG_MAIN
				//printf("FoundConicModel\n\r");
			#endif
			MtxCV::classifyConic(best_conic);
		}

		HAL_GPIO_TogglePin(GPIOB, GPIO_LED1_GRN_OUTPUT_Pin); // TOGGLE onboard LED each loop

	/* USER CODE END WHILE */

	/* USER CODE BEGIN 3 */

	}
	/* USER CODE END 3 */
}

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
/* USER CODE BEGIN 4 */
/* COMMENTED AS FUNCTION IS RELATED TO TESTING

*/

bool initialise_MLX90640(const uint8_t& I2C_address, paramsMLX90640& _paramsTarget) {
/*	//Typedef different sensor operation modes
	typedef enum MLX90640_Mode {
		MLX90640_INTERLEAVED, //image read in interleaved lines (odd rows, even rows etc)
		MLX90640_CHESS // [default] image read in chess pattern (odd index, even index etc)
	};

	//Typedef different sensor resolutions for pixel ADC reading
	typedef enum MLX90640_Resolution {
		MLX90640_ADC_16BIT,
		MLX90640_ADC_17BIT,
		MLX90640_ADC_18BIT, // [default]
		MLX90640_ADC_19BIT
	};

	//Typedef different sensor supported refresh rates
	typedef enum MLX90640_RefreshRate {
		MLX90640_0_5HZ,
		MLX90640_1HZ,
		MLX90640_2HZ, // [default]
		MLX90640_4HZ,
		MLX90640_8HZ,
		MLX90640_16HZ,
		MLX90640_32HZ,
		MLX90640_64HZ
	};
*/

	//Check if MLX90640 is available at I2C address
	if (!MLX90640_isConnected(I2C_address)) {
		#ifdef _DEBUG_SENSOR
			printf("[Err] MLX90640 not detected at 0x%x I2C address.\n\r", I2C_address);
		#endif
		return false;
	} else {
		#ifdef _DEBUG_SENSOR
			printf("OK: MLX90640 I2C online!\n\r");
		#endif
	}

	// Dump parameters from MLX90640 EEPROM
	uint16_t eeMLX90640[MLX_EEPROM_SIZE]; // EEPROM dump from thermal camera parameters, used in thermal array API calcs
	int eeDumpState = MLX90640_DumpEE(I2C_address, eeMLX90640);
	if (eeDumpState != 0) {
		#ifdef _DEBUG_SENSOR
			// -1 indicates NACK occurred during the communication and eeMLX90640 is invalid EEPROM data
			printf("[Err] Failed to dump EEPROM. Return code [%d].\n\r", eeDumpState);
		#endif
		return false;
	} else {
		#ifdef _DEBUG_SENSOR
			printf("OK: MLX90640 EEROM dumped successfully.\n\r");
		#endif
	}

	int getParamsState = MLX90640_ExtractParameters(eeMLX90640, &_paramsTarget);
	if (getParamsState != 0) {
		//eeMLX90640 is not valid, the parameters extraction is aborted
		// -3: MLX90640_BROKEN_PIXELS_NUM_ERROR, -4: MLX90640_OUTLIER_PIXELS_NUM_ERROR, -5: MLX90640_BAD_PIXELS_NUM_ERROR, -6: CheckAdjacentPixels failed check
		#ifdef _DEBUG_SENSOR
			printf("[Err] Failed to extract parameters. Return code [%d].\n\r", getParamsState);
		#endif
		return false;
	} else {
		#ifdef _DEBUG_SENSOR
			printf("OK: MLX90640 parameters extracted!\n\r");
		#endif
	}

	//Check sensor current mode and re-configure if not as expected
	int deviceSetting = MLX90640_GetCurMode(I2C_address); //return 0 is interleaved mode, 1 is chess pattern mode
	if(deviceSetting != (int)MLX90640_Mode::MLX90640_CHESS) {
		int returnCode = MLX90640_SetChessMode(I2C_address);
		if(returnCode != 0) {
			#ifdef _DEBUG_SENSOR
				printf("[Err] Failed to set mode to [%u]. Return code [%d].\n\r", (int)MLX90640_Mode::MLX90640_CHESS, returnCode);
			#endif
//			return false;
		} else {
			#ifdef _DEBUG_SENSOR
				printf("OK: Re-configured device to reading mode: MLX90640_CHESS\n\r");
			#endif
		}
	} else {
		#ifdef _DEBUG_SENSOR
			printf("OK: Device is already in reading mode: MLX90640_CHESS\n\r");
		#endif
	}


	//Check sensor current pixel ADC resolution and re-configure if not as expected
	deviceSetting = MLX90640_GetCurResolution(I2C_address); // see MLX90640_Resolution typedef
	if(deviceSetting != (int)MLX90640_Resolution::MLX90640_ADC_18BIT) {
		int returnCode = MLX90640_SetResolution(I2C_address, (uint8_t)MLX90640_Resolution::MLX90640_ADC_18BIT);
		if(returnCode != 0) {
			#ifdef _DEBUG_SENSOR
				printf("[Err] Failed to set ADC resolution to [%u]. Return code [%d].\n\r", (int)MLX90640_Resolution::MLX90640_ADC_18BIT, returnCode);
			#endif
//			return false;
		} else {
			#ifdef _DEBUG_SENSOR
				printf("OK: Re-configured device to ADC resolution: MLX90640_ADC_18BIT\n\r");
			#endif
		}
	} else {
		#ifdef _DEBUG_SENSOR
			printf("OK: Device is already set to ADC resolution: MLX90640_ADC_18BIT\n\r");
		#endif
	}

	//Check sensor current pixel ADC resolution and re-configure if not as expected
	deviceSetting = MLX90640_GetRefreshRate(I2C_address); // see MLX90640_Resolution typedef
	if(deviceSetting != (int)MLX90640_RefreshRate::MLX90640_8HZ) {
		int returnCode = MLX90640_SetRefreshRate(I2C_address, (uint8_t)MLX90640_RefreshRate::MLX90640_8HZ);
		if(returnCode != 0) {
			#ifdef _DEBUG_SENSOR
				printf("[Err] Failed to set refresh rate to [%u]. Return code [%d].\n\r", (int)MLX90640_RefreshRate::MLX90640_8HZ, returnCode);
			#endif
//			return false;
		} else {
			#ifdef _DEBUG_SENSOR
				printf("OK: Re-configured device to refresh rate: MLX90640_8HZ\n\r");
			#endif
		}
	} else {
		#ifdef _DEBUG_SENSOR
			printf("OK: Device is already set to refresh rate: MLX90640_8HZ\n\r");
		#endif
	}


	return true; //(eeDumpState == 0 && getParamsState == 0);

}

/*Helper function to load thermal image array from subpage 1 and 2.*/
int getFrame_MLX90640(const uint8_t& I2C_address, float *_imgArr, float& _ta, paramsMLX90640& _params) { //, MLXFrameProgress& _getImgState
	// New Subpage is avaiable every 1/FPS, eg MLX90640_8HZ is new subPage every 125ms, meaning a full page is ready every 250ms
	// as per amanufacturer: time necessary before the device can reach the specified accuracy ~4 min.
	int status = -1; //track results of sensor related function executions
	uint16_t mlx90640Frame[MLX_FRAME_DATA_SIZE]; //temp storage for 1D image frame from sensor

	// for both subframes of complete image
	for (uint8_t page = 0; page < 2; page++) {
		//extract subframe (#1, then #2) to mlx90640Frame
		status = MLX90640_GetFrameData(I2C_address, mlx90640Frame);
		//Verify if extraction ok
		if (status < 0) {
			#ifdef _DEBUG_SENSOR
				printf("[Err]@getFrame_MLX90640 return code: %d\n\r", status);
			#endif
			return status;
		}
		//Construct image from both sub frame #1 and #2
		MLX90640_GetImage(mlx90640Frame, &_params, _imgArr);
		HAL_Delay(200); // TBD move this functionality to I2C interrupt: Delay for debug testing, give time for next subpage to be prepared
	}
	// Perform broken pixel and outlier adjustement to image
	int mode = MLX90640_GetCurMode(I2C_address);
	MLX90640_BadPixelsCorrection((&_params)->brokenPixels, _imgArr, mode, &_params);
	MLX90640_BadPixelsCorrection((&_params)->outlierPixels, _imgArr, mode, &_params);
	return 0; //success
}


// Helper function to send edge sequence to serial, to display as graph on host machine
void sendGraphCoords(const vector<EdgePoint*>& edgeContour) {
	// Get the number of coords in the current edge sequence
	//size_t numCoords = edgeContour.size();
	// Init matrix to send coords via serial as [x, y, x_adjusted, y_adjusted],[...
	MatrixXf coordData(edgeContour.size(), 4);
	// Loop over coord and coord adjustements in current edge sequence and fill the matrix
	for (size_t edgeCoordIndex = 0; edgeCoordIndex < edgeContour.size(); ++edgeCoordIndex) {
		const EdgePoint* edge = edgeContour[edgeCoordIndex];
		// Fill the matrix with x, y, x_adjusted, and y_adjusted
		coordData(edgeCoordIndex, 0) = static_cast<float>(edge->coord.x());      // x_coord
		coordData(edgeCoordIndex, 1) = static_cast<float>(edge->coord.y());     // y_coord
		coordData(edgeCoordIndex, 2) = edge->adjustment.x();                     // x_adjusted
		coordData(edgeCoordIndex, 3) = edge->adjustment.y();                    // y_adjusted
	}
	sendMatrixSerial(coordData, "graph"); //send edge coords and adjustement via serial as graph data
}

// Function to send data over serial using HAL libraries
void sendSerialData(const uint8_t* data, uint16_t size) {
	const size_t timeout_ms = 3000;
    // Replace USART2 with the appropriate USART instance you're using
    HAL_UART_Transmit(&hlpuart1, (uint8_t*)data, size, timeout_ms);
	//printf("%s", data);
}

// Function to send image matrix via serial in CSV format
template<typename MatrixType>
void sendMatrixSerial(const MatrixType& matrix, const char* uniqueTitle) {
	const int defaultPrecision = 2;
	const Index mtxRows = matrix.rows();
    const Index mtxCols = matrix.cols();
    bool isFloatingPoint = std::is_floating_point<typename MatrixType::Scalar>::value;
    int decimalPrecision = (isFloatingPoint ? defaultPrecision : 0);

    // Prepare tagData / buffer string
    char sendBuffer[mtxCols * 10]; //
    size_t buffSize = sizeof(sendBuffer);
    int charWritten = snprintf(sendBuffer, buffSize, "~txBEG~{ID:%s,X:%d,Y:%d,dt:%s}\n", uniqueTitle, mtxCols, mtxRows, (isFloatingPoint ? "f" : "i"));
    // if the provided title overflows the buffer, instead send the unique matrix memory address in its place
    if (charWritten < 0 || charWritten >= static_cast<int>(buffSize)) {
    	const void* matrixAddress = static_cast<const void*>(&matrix);
    	snprintf(sendBuffer, buffSize, "~txBEG~{ID:%p,X:%d,Y:%d,dt:%s}\n", matrixAddress, mtxCols, mtxRows, (isFloatingPoint ? "f" : "i"));
    }
    // Send serial start designator and matrix tagData
    sendSerialData(reinterpret_cast<const uint8_t*>(sendBuffer), strlen(sendBuffer));

    size_t offset = 0;

    // Iterate over each row of the image matrix
    for (Index j = 0; j < mtxRows; ++j) {
		// Iterate over each column of the image matrix
		for (Index i = 0; i < mtxCols; ++i) {
			// Convert each pixel value to string and copy to the buffer
			//offset += snprintf(buffer + offset, sizeof(buffer) - offset, "%.*f,", decimalPrecision, static_cast<float>(matrix(j, i)));
			// Convert each pixel value to string and copy to the buffer
			int charWritten = snprintf(sendBuffer + offset, buffSize - offset, "%.*f,", decimalPrecision, static_cast<float>(matrix(j, i)));
			if (charWritten < 0 || charWritten >= static_cast<int>(buffSize - offset)) {
				// [Err]: Buffer overflow while formatting row
			    // Send serial ERROR designator
			    snprintf(sendBuffer, buffSize, "~txERR~\n\r");
			    sendSerialData(reinterpret_cast<const uint8_t*>(sendBuffer), strlen(sendBuffer));
			    return;
			} else {
				offset += charWritten;
			}
		}
        // Add newline character at the end of each row if there's space in the buffer
        if (offset + 1 < buffSize) {
        	// Add newline character at the end of each row
        	sendBuffer[offset - 1] = ';'; // Replace the last comma with semicolon
        	sendBuffer[offset++] = '\n'; // Add newline character
        } else {
            // Buffer overflow, send error designator and return
            snprintf(sendBuffer + offset, buffSize - offset, "~txERR~\n\r");
            sendSerialData(reinterpret_cast<const uint8_t*>(sendBuffer), strlen(sendBuffer));
            return;
        }
        //sendBuffer[offset - 1] = ';'; // Replace the last comma with semicolon
		// Send the buffer over serial port
		sendSerialData(reinterpret_cast<const uint8_t*>(sendBuffer), offset);
		offset = 0; // Reset offset for the next row
    }

    // Send serial end designator
    snprintf(sendBuffer, buffSize, "~txEND~\n\r");
    sendSerialData(reinterpret_cast<const uint8_t*>(sendBuffer), strlen(sendBuffer));
}

// pseudo "random" number from current ms since program start
unsigned int getSysTickSeed(void) {
    return HAL_GetTick(); // Get the current tick count as a seed
}

/* COMMENTED AS FUNCTIONS BELOW ARE RELATED TO DEBUG / TESTING
//Testing function to load matrix with incrementing numbers
void fillMatrixIncrementing(MatrixXi& matrix, const int startingSeed = 1, const int stepDistance = 1) {
    Eigen::Index rows = matrix.rows();
    Eigen::Index cols = matrix.cols();
    int value = startingSeed;
    for (Eigen::Index j = 0; j < rows; ++j) {
        for (Eigen::Index i = 0; i < cols; ++i) {
            value += stepDistance;
            matrix(j, i) = value;
        }
    }
}

// Function to print data in binary format
void printBinary(uint16_t& data, bool newLineAfter = true) {
    for (int i = 15; i >= 0; i--) {
        printf("%d", (data >> i) & 0x01);
    }
    if(newLineAfter){
    	 printf("\n\r");
    }
}
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

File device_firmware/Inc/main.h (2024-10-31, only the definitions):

#define RCC_OSC32_LSClock_IN_OUT_Pin GPIO_PIN_14
#define RCC_OSC32_LSClock_IN_OUT_GPIO_Port GPIOC
#define RCC_OSC32_LSClock_OUT_IN_Pin GPIO_PIN_15
#define RCC_OSC32_LSClock_OUT_IN_GPIO_Port GPIOC
#define RCC_OSC_HSClock_IN_OUT_Pin GPIO_PIN_0
#define RCC_OSC_HSClock_IN_OUT_GPIO_Port GPIOH
#define RCC_OSC_HSClock_OUT_IN_Pin GPIO_PIN_1
#define RCC_OSC_HSClock_OUT_IN_GPIO_Port GPIOH
#define LPUART_DEBUG_TX_Pin GPIO_PIN_2
#define LPUART_DEBUG_TX_GPIO_Port GPIOA
#define LPUART_DEBUG_RX_Pin GPIO_PIN_3
#define LPUART_DEBUG_RX_GPIO_Port GPIOA
#define SPI1_CS_Pin GPIO_PIN_0
#define SPI1_CS_GPIO_Port GPIOB
#define GPIO_EXT_PWM_INPUT_PB12_Pin GPIO_PIN_12
#define GPIO_EXT_PWM_INPUT_PB12_GPIO_Port GPIOB
#define GPIO_EXT_INTERRUPT_PB13_Pin GPIO_PIN_13
#define GPIO_EXT_INTERRUPT_PB13_GPIO_Port GPIOB
#define GPIO_EXT_INTERRUPT_PB13_EXTI_IRQn EXTI15_10_IRQn
#define GPIO_SW2_INPUT_Pin GPIO_PIN_8
#define GPIO_SW2_INPUT_GPIO_Port GPIOA
#define I2C1_SCL_IR_SENSOR_Pin GPIO_PIN_9
#define I2C1_SCL_IR_SENSOR_GPIO_Port GPIOA
#define I2C1_SDA_IR_SENSOR_Pin GPIO_PIN_10
#define I2C1_SDA_IR_SENSOR_GPIO_Port GPIOA
#define GPIO_LED2_YEL_OUTPUT_Pin GPIO_PIN_5
#define GPIO_LED2_YEL_OUTPUT_GPIO_Port GPIOB
#define GPIO_LED1_GRN_OUTPUT_Pin GPIO_PIN_6
#define GPIO_LED1_GRN_OUTPUT_GPIO_Port GPIOB

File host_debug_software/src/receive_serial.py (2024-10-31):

import serial # recieve COM port serial data from device
import cv2 # openCV for interpretting received matrix data as renderable image
import matplotlib.pyplot as plt # plot graph data; requires pip install matplotlib
from matplotlib.animation import FuncAnimation # attempt at getting an interractive graph that can be moved around while updating..TBD proper implementation
import numpy as np # maths and matrix library
import threading # parallel execution for reading COM serial and processing queue tasks
import queue # queue inbound tasks based on received serial data
import sys # receive execution arguments, eg for COM port selection

# Global variables
_DEBUG_RECEIVE = True #False # debug flag, set false to turn off debug

mtx_data_queue = queue.Queue()  # Queue for passing matrix data between threads
mtx_displayed = {}  # Keep track of displayed matrices and their window names

def receive_matrix_data(port):
    ser = serial.Serial(port, 115200) #begin serial on port @baudRate
    while True:
        line = ser.readline().strip()  # Read binary data
        # check for comms convention tag
        if line.startswith(b'~txBEG~'):
            print("Receiving matrix...")
            metadata = line.split(b'{')[1].split(b'}')[0]
            meta_dict = {}
            # extract matrix metadata from transmission
            for pair in metadata.split(b','):
                key, value = pair.split(b':')
                meta_dict[key.strip()] = value.strip()
            # print("Metadata:", meta_dict)      
            mtxID = meta_dict[b'ID']
            rows = int(meta_dict[b'Y'])
            cols = int(meta_dict[b'X'])
            dtype = meta_dict[b'dt']

            print("metadata:{{ID:{} {}cols X {}rows of type {}}}".format(mtxID, cols, rows, dtype))
            # stage serial matrix data, also print data to terminal if debug flag is set
            matrix_data = b""
            while True:
                line = ser.readline().strip()
                if _DEBUG_RECEIVE:
                    print("Received line:", line)  
                if line == b"~txEND~" or line == b"~txERR~":
                    break
                matrix_data += line
            # split by rows and construct matrix from recieved data
            matrix_flat = matrix_data.split(b';') 
            matrix = np.zeros((rows, cols), dtype=np.float32) # if dtype == b'f' else np.float32)
            for i, row in enumerate(matrix_flat):
                if row.strip() != b'':
                    row_data = row.split(b',')
                    for j, val in enumerate(row_data):
                        try:
                            matrix[i, j] = float(val) # if dtype == b'f' else float(val)
                        except ValueError as e:
                            print("Error: Matrix transfer interrupted or invalid matrix datatype:", val)

            mtx_data_queue.put((mtxID, matrix))  # Put the received matrix in the queue

        elif line == b'~txERR~':
            print("Error: Matrix transfer interrupted or invalid, received ~txERR~ tag from sender.")
        elif line == b'~txEND~':
            if _DEBUG_RECEIVE:
                print("End of matrix transfer tag ~txEND~ recieved without ~txBEG~ begin tag.")
        else:
            # Pass through any other received serial commands directly to terminal
            print("DEVICE SAYS:", line)

# render matrix to openCV window; each unique ID received is rendered to a new window, if the same ID is seen again the existing window is updated instead
def display_matrix(matrix_id, matrix):
    try:
        min_val = np.min(matrix)
        max_val = np.max(matrix)
        if min_val < 0 or max_val > 255:
            scaled_matrix = cv2.normalize(matrix, None, 0, 255, norm_type=cv2.NORM_MINMAX, dtype=cv2.CV_8U)
        else:
            scaled_matrix = matrix.astype(np.uint8)
        # <<IMAGE COLOUR OPTIONS>>
        # COLORMAP_AUTUMN red to yellow
        # COLORMAP_BONE  black to white
        # COLORMAP_JET blue to green to red
        # COLORMAP_WINTER  blue to cyan
        # COLORMAP_RAINBOW  spectrum
        # COLORMAP_OCEAN  white to blue
        # COLORMAP_SUMMER  green to yellow
        img0 = cv2.applyColorMap(scaled_matrix, cv2.COLORMAP_JET)
        
        # TBD flips REMOVE, doing here as easier than micro due memory
        # Perform horizontal and vertical flip (both axes)
        img = cv2.flip(img0, -1)
        
        # target px width for rescale
        targetWidth_px = 640 
        scaleFactor = targetWidth_px / img.shape[1] # scale factor required to achieve target
        # calculate new dimensions
        width = int(img.shape[1] * scaleFactor) # target 640 width
        height = int(img.shape[0] * scaleFactor)
        resize_dim = (width, height)
        img_resize = cv2.resize(img, resize_dim, interpolation = cv2.INTER_NEAREST)

        # mtxID_str = mtxID.decode('utf-8')  # Decode byte string to regular string
        if matrix_id in mtx_displayed:
            cv2.imshow(mtx_displayed[matrix_id], img_resize)
        else:
            cv2.imshow(matrix_id, img_resize)
            mtx_displayed[matrix_id] = matrix_id
        cv2.waitKey(1)
    except queue.Empty:
        pass

# init graph with axis range bounds and render position on screen
def init_plot(x_range=(-160, 160), y_range=(-120, 120), position=(0, 550)): #ORIGINAL PIXELS: (x_range=(0, 32), y_range=(24, 0)):
    # init the plot using matplotlib
    fig, ax = plt.subplots(figsize=(8, 6))  # figsize=(8, 6) fig is the container, ax is the plot area

    # Create empty lines for original and adjusted coordinates
    original_line, = ax.plot([], [], label='EdgeCoord', marker='o', linestyle='-', color='blue')
    adjusted_line, = ax.plot([], [], label='Adjusted', marker='x', linestyle='--', color='red', markersize = 8)
    # original_line, = ax.plot(
        # x_values, y_values, 
        # label='lineName', 
        # marker='^', 
        # linestyle='--', 
        # color='red', 
        # linewidth=2, 
        # markersize=8, 
        # markerfacecolor='yellow', 
        # markeredgecolor='black'
    # )
    # Set labels, title, and legend
    ax.set_xlabel('X')
    ax.set_ylabel('Y')
    ax.set_title('EdgeCoord and Adjustment')
    ax.legend()

    # Set fixed axis limits for the graph
    ax.set_xlim(x_range)  # Set the range for the X-axis
    ax.set_ylim(y_range)  # Set the range for the Y-axis
    
    # Move the plot window to the desired position
    fig.canvas.manager.window.wm_geometry(f"+{position[0]}+{position[1]}")
    
    return fig, ax, original_line, adjusted_line
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

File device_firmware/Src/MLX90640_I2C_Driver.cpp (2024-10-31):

/*
 * MLX90640_I2C_Driver.cpp
 *
 *  Created on: Apr 14, 2024
 *      Author: AJ
 */
#include "MLX90640_I2C_Driver.h"
/* ## I2C HAL Callback Functions for Interrupt Mode ##
HAL_I2C_MasterTxCpltCallback(): callback when the master transmission process is complete.
HAL_I2C_MasterRxCpltCallback(): callback when the master reception process is complete.
HAL_I2C_SlaveTxCpltCallback(): callback when the slave transmission process is complete.
HAL_I2C_SlaveRxCpltCallback(): callback when the slave reception process is complete.
HAL_I2C_AddrCallback(): callback when the slave address matched with the received address.
HAL_I2C_ListenCpltCallback(): callback when the complete slave transfer is done, and the slave is set to listen mode.
HAL_I2C_ErrorCallback():  callback when an error occurs during the I2C communication.
*/
//create static pointer to I2C typedef, this is initialised in the main.c and passed to this header via MLX90640_I2CInit()
static I2C_HandleTypeDef *hi2cPtr; // Pointer to store the reference to hi2cX
static bool I2CPtrInit = false;

// Initialise  MLX90640_I2C_Driver.h with reference to hi2c1, this reference is stored and used to transmit and recieve data
void MLX90640_I2CInitRef(I2C_HandleTypeDef *hi2c) {
	if(hi2c != nullptr) {
		hi2cPtr = hi2c; // Store the reference to hi2c1
		I2CPtrInit = true;
		#ifdef _DEBUG_I2C_DRIVER
			printf("OK: I2C endpoint reference configured.\n\r");
		#endif
	} else {
		#ifdef _DEBUG_I2C_DRIVER
			printf("[Err] No I2C endpoint configured: I2CInitRef(&hi2cX) == NULL.\n\r");
		#endif
	}
}

//Check if device at given address is returning an ACK flag on the current I2C interface hi2cPtr reference
bool MLX90640_isConnected(uint8_t slaveAddr) {
    // Check if hi2cPtr reference is set and not NULL
    if (!I2CPtrInit) {
		#ifdef _DEBUG_I2C_DRIVER
    		printf("[Err] No I2C endpoint configured: I2CInitRef(&hi2cX) == NULL.\n\r");
		#endif
        return false; // I2C pointer reference not initialised, return error
    }
    uint16_t address = slaveAddr << 1; // Shift the address left by 1 to include the R/W bit

    // Attempt to start an I2C transmission to the device
    //DEFINITION: HAL_StatusTypeDef HAL_I2C_IsDeviceReady(I2C_HandleTypeDef *hi2c, uint16_t DevAddress, uint32_t Trials, uint32_t Timeout)
    HAL_StatusTypeDef status = HAL_I2C_IsDeviceReady(hi2cPtr, address, 2, MLX90640_TIMEOUT_MS);
    if (status != HAL_OK) {
		#ifdef _DEBUG_I2C_DRIVER
    		printf("[Err] Device I2C isConnected test did not ACK: "); printHALStatus(status);
		#endif
        return false; // Sensor did not ACK
    } else {
		#ifdef _DEBUG_I2C_DRIVER
			printf("Device I2C isConnected test returned: "); printHALStatus(status);
		#endif
        return true; // Sensor detected
    }
}
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

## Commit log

2024-10-31 Restore local files
    [BaseStructure_v55.stl, BearingSpacerInsert_v55.stl, PartsList.xlsx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]
2024-11-13 Add program execution flowchart
2024-11-13 Update README.md
    added example program execution flowchart

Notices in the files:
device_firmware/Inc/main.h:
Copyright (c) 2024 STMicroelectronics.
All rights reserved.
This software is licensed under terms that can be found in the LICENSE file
